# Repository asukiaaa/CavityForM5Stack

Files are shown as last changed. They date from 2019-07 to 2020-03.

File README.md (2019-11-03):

# CavityForM5Stack

PCBs to create a cavity for M5Stack.

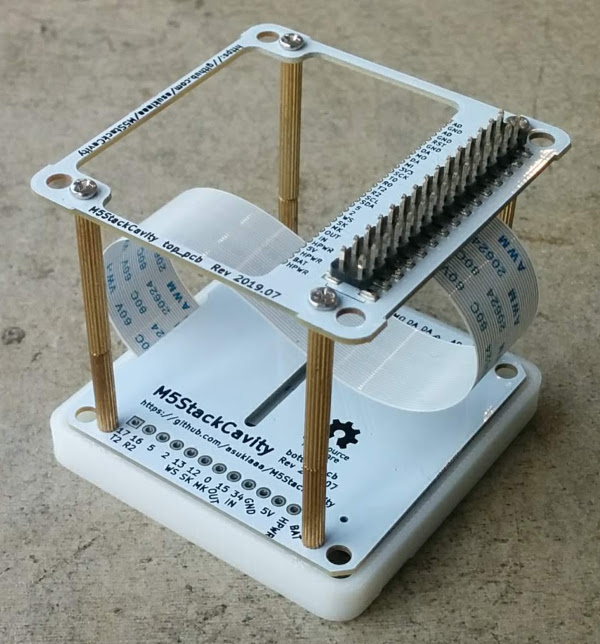
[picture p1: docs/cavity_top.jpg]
cavity_top

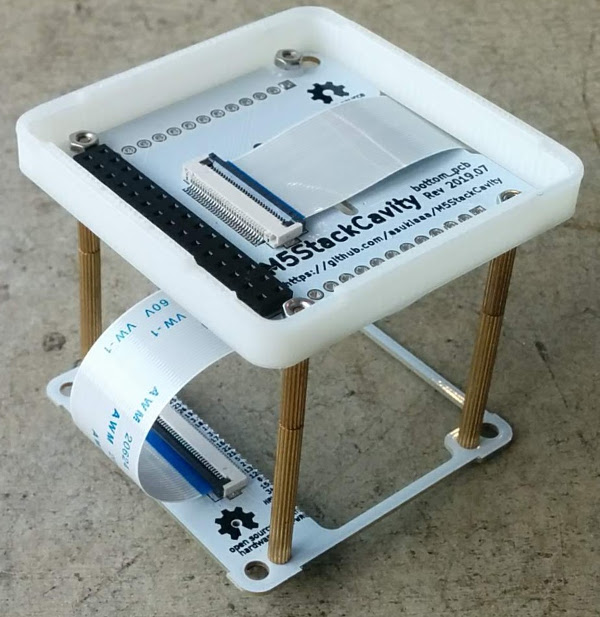
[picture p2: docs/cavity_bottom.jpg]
cavity_bottom


# License

MIT

# References

- [CavityForM5Stack ピンソケット、ブレッドボード無し](https://www.switch-science.com/catalog/5684/)
- [CavityForM5Stack ピンソケット、ブレッドボード付き](https://www.switch-science.com/catalog/5685/)
- [M5StackのStackに背の高い部品を利用できるM5StackCavityを作ってみた](http://asukiaaa.blogspot.com/2019/08/m5stackstackm5stackcavity.html)

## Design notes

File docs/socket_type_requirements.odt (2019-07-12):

Put header for top_pcb and put socket for bottom_pcb.

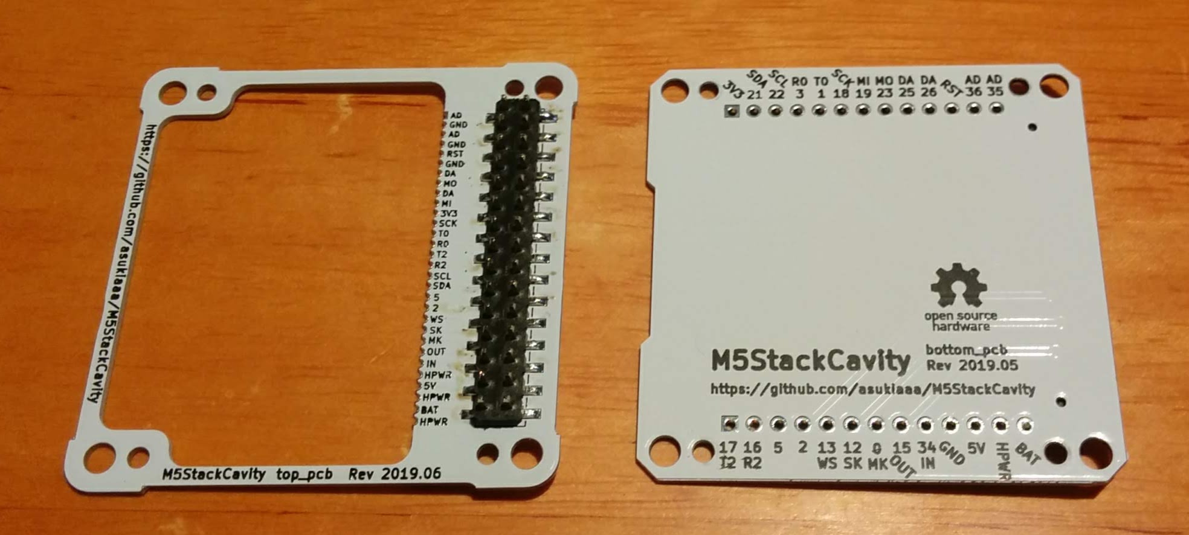
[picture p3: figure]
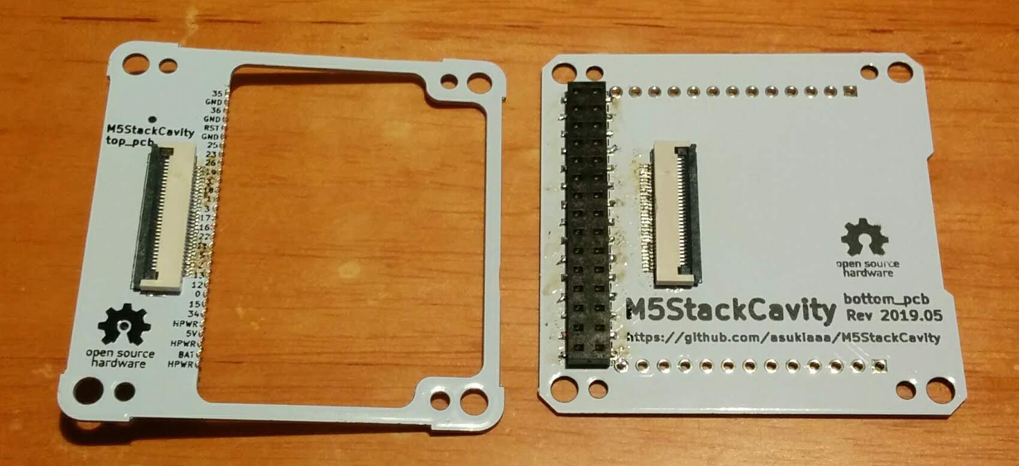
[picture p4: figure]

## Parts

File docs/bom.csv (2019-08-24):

Name | Number | Url | Memo
top_pcb | 1 | Attached | Layer--2layers PCB Thickness--1.0mm Dimensions--51mm * 51mm Castellated Hole--Yes PCB Color--White Surface Finish--HASL Lead Free Copper Weight--1oz Different Design:--1
bottom_pcb | 1 | Attached | Layer--2layers PCB Thickness--1.0mm Dimensions--50mm * 50mm Castellated Hole--No PCB Color--White Surface Finish--HASL Lead Free Copper Weight--1oz Different Design:--1
M5 Stack Joint | 1 pair | https://ja.aliexpress.com/store/product/M5Stack-Official-Stock-Offer-2x15-Pin-Headers-Socket-2-54mm-Male-Female-4-Pair-Connector-for/3226069_32840923472.html | Use header for top_pcb, socket for bottom_pcb
0.5mm pitch 30 pins FPC Connector | 2 | https://ja.aliexpress.com/item/32956902542.html
2.54m pitch 1x13 PinSocket white | 2 |  | Put pinsocket on front side of bottom_pcb. I don't mind bendor.

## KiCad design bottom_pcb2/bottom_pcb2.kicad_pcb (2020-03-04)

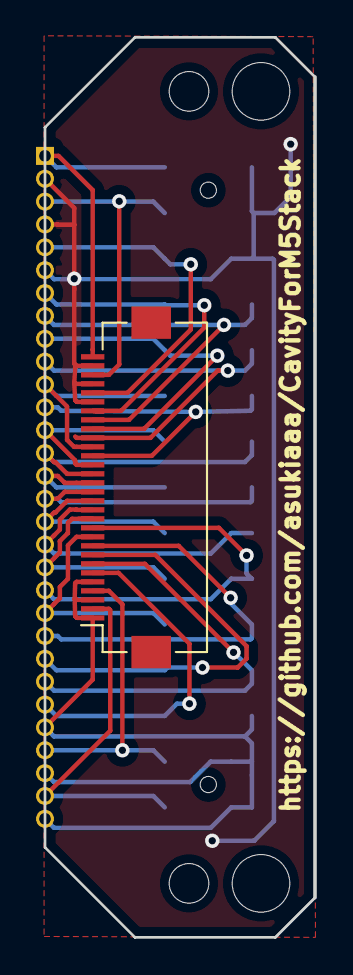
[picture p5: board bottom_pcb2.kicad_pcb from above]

Board: 2 copper layers, 15.0 x 50.0 mm, 7 parts (1 on the bottom side), 26 nets.

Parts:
J1: socket; PinSocket_2x15_P2.54mm_Vertical_SMD_just_for_M5Stack_bottom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
J3: free_holes; PinHeader_1x30_P1.27mm_Vertical_without_silks
Jv: flat_cable_connector; Hirose_FH12-30S-0.5SH_1x30-1MP_P0.50mm_Horizontal
REF3, REF8: MountingHole_2.2mm_M2
REF4, REF9: MountingHole_3.2mm_M3

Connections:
+3V3: J1.11, J3.11, Jv.20
+5V: J1.27, J3.27, Jv.4
+BATT: J1.29, J3.29, Jv.2
G0: J1.23, J3.23, Jv.8
G1: J1.13, J3.13, Jv.18
G2: J1.20, J3.20, Jv.11
G3: J1.14, J3.14, Jv.17
G5: J1.19, J3.19, Jv.12
G12: J1.22, J3.22, Jv.9
G13: J1.21, J3.21, Jv.10
G15: J1.24, J3.24, Jv.7
G16: J1.16, J3.16, Jv.15
G17: J1.15, J3.15, Jv.16
G18: J1.12, J3.12, Jv.19
G19: J1.10, J3.10, Jv.21
G21: J1.18, J3.18, Jv.13
G22: J1.17, J3.17, Jv.14
G23: J1.8, J3.8, Jv.23
G25: J1.7, J3.7, Jv.24
G26: J1.9, J3.9, Jv.22
G34: J1.25, J3.25, Jv.6
G35: J1.1, J3.1, Jv.30
G36: J1.3, J3.3, Jv.28
GND: J1.2, J1.4, J1.6, J3.2, J3.4, J3.6, Jv.25, Jv.27, Jv.29
HPWR: J1.26, J1.28, J1.30, J3.26, J3.28, J3.30, Jv.1, Jv.3, Jv.5
RST: J1.5, J3.5, Jv.26

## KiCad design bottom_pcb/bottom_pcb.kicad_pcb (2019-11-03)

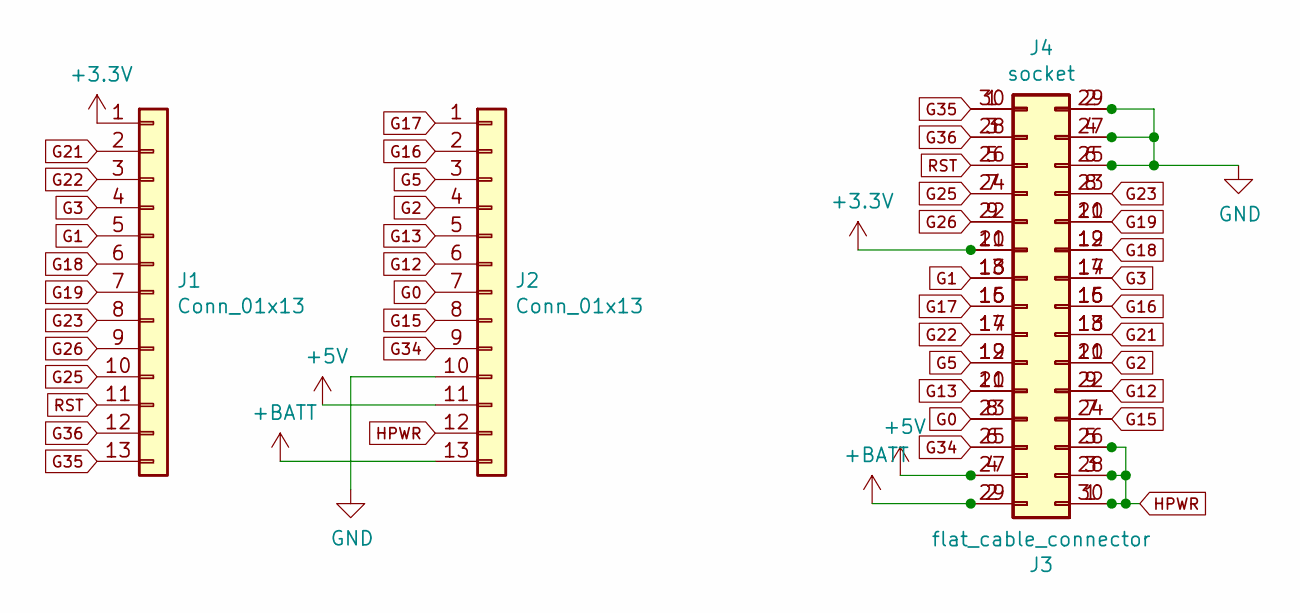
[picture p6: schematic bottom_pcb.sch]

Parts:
J1, J2: Conn_01x13; PinSocket_1x13_P2.54mm_Vertical_without_silks
J3: flat_cable_connector; Hirose_FH12-30S-0.5SH_1x30-1MP_P0.50mm_Horizontal
J4: socket; PinSocket_2x15_P2.54mm_Vertical_SMD_just_for_M5Stack_bottom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

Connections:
+3V3: J1.1, J3.20, J4.11
+5V: J2.11, J3.4, J4.27
+BATT: J2.13, J3.2, J4.29
G0: J2.7, J3.8, J4.23
G1: J1.5, J3.18, J4.13
G2: J2.4, J3.11, J4.20
G3: J1.4, J3.17, J4.14
G5: J2.3, J3.12, J4.19
G12: J2.6, J3.9, J4.22
G13: J2.5, J3.10, J4.21
G15: J2.8, J3.7, J4.24
G16: J2.2, J3.15, J4.16
G17: J2.1, J3.16, J4.15
G18: J1.6, J3.19, J4.12
G19: J1.7, J3.21, J4.10
G21: J1.2, J3.13, J4.18
G22: J1.3, J3.14, J4.17
G23: J1.8, J3.23, J4.8
G25: J1.10, J3.24, J4.7
G26: J1.9, J3.22, J4.9
G34: J2.9, J3.6, J4.25
G35: J1.13, J3.30, J4.1
G36: J1.12, J3.28, J4.3
GND: J2.10, J3.25, J3.27, J3.29, J4.2, J4.4, J4.6
HPWR: J2.12, J3.1, J3.3, J3.5, J4.26, J4.28, J4.30
RST: J1.11, J3.26, J4.5

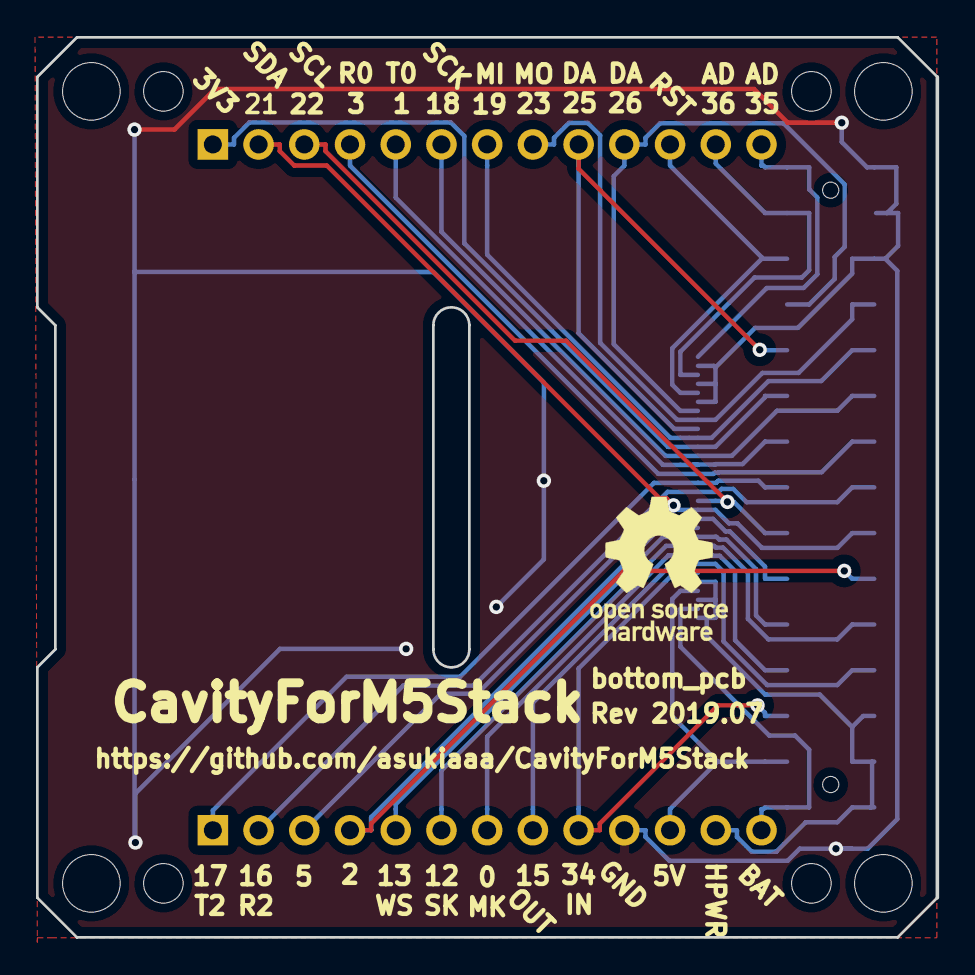
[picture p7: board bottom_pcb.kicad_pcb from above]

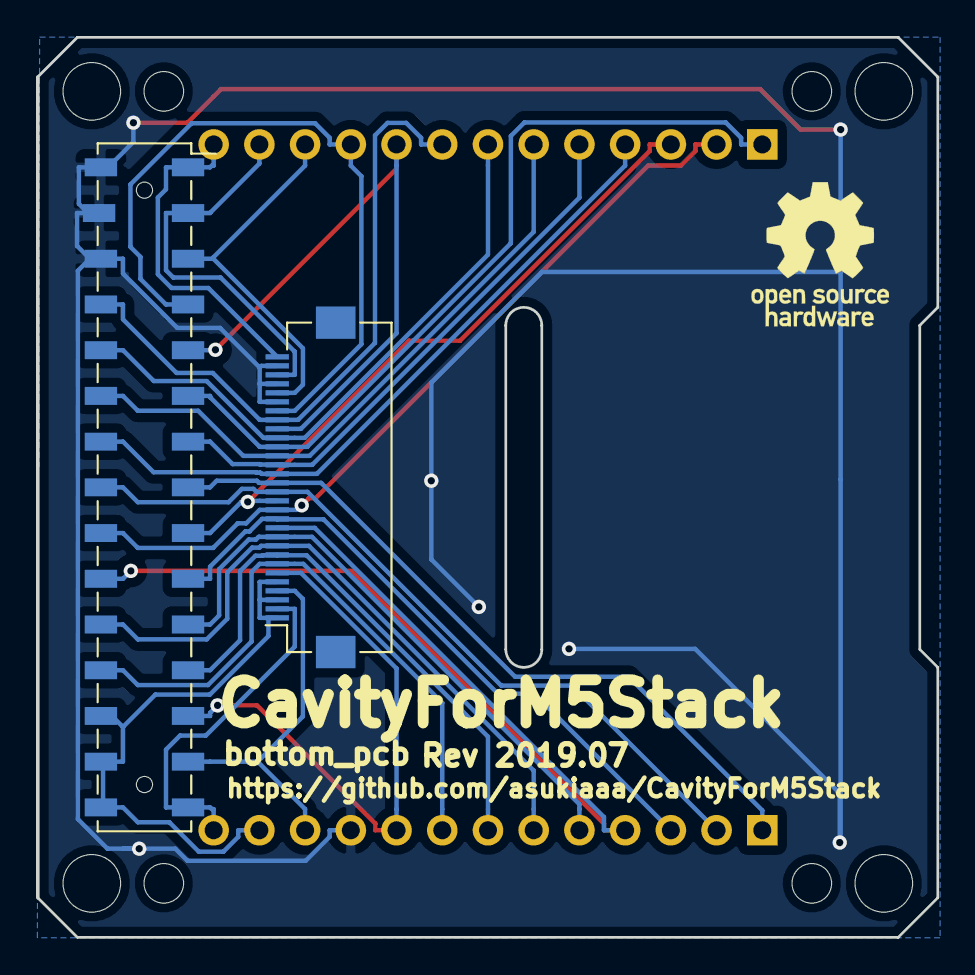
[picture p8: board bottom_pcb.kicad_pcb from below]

Board: 2 copper layers, 50.0 x 50.0 mm, 14 parts (3 on the bottom side), 26 nets.

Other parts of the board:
OSHWREF1, OSHWREF2: OSHW-Logo_7.5x8mm_SilkScreen
REF1, REF4, REF6, REF9: MountingHole_3.2mm_M3
REF2, REF3, REF7, REF8: MountingHole_2.2mm_M2

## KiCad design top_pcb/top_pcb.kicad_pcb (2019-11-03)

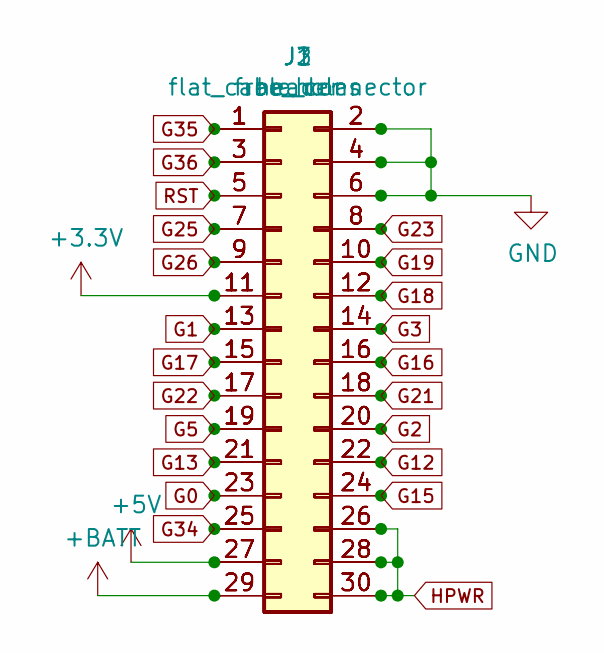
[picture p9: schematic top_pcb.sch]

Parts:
J1: flat_cable_connector; Hirose_FH12-30S-0.5SH_1x30-1MP_P0.50mm_Horizontal
J2: header; PinHeader_2x15_P2.54mm_Vertical_SMD_for_M5Stack
J3: free_holes; PinHeader_1x30_P1.27mm_Vertical_without_silks

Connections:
+3V3: J1.11, J2.11, J3.11
+5V: J1.27, J2.27, J3.27
+BATT: J1.29, J2.29, J3.29
G0: J1.23, J2.23, J3.23
G1: J1.13, J2.13, J3.13
G2: J1.20, J2.20, J3.20
G3: J1.14, J2.14, J3.14
G5: J1.19, J2.19, J3.19
G12: J1.22, J2.22, J3.22
G13: J1.21, J2.21, J3.21
G15: J1.24, J2.24, J3.24
G16: J1.16, J2.16, J3.16
G17: J1.15, J2.15, J3.15
G18: J1.12, J2.12, J3.12
G19: J1.10, J2.10, J3.10
G21: J1.18, J2.18, J3.18
G22: J1.17, J2.17, J3.17
G23: J1.8, J2.8, J3.8
G25: J1.7, J2.7, J3.7
G26: J1.9, J2.9, J3.9
G34: J1.25, J2.25, J3.25
G35: J1.1, J2.1, J3.1
G36: J1.3, J2.3, J3.3
GND: J1.2, J1.4, J1.6, J2.2, J2.4, J2.6, J3.2, J3.4, J3.6
HPWR: J1.26, J1.28, J1.30, J2.26, J2.28, J2.30, J3.26, J3.28, J3.30
RST: J1.5, J2.5, J3.5

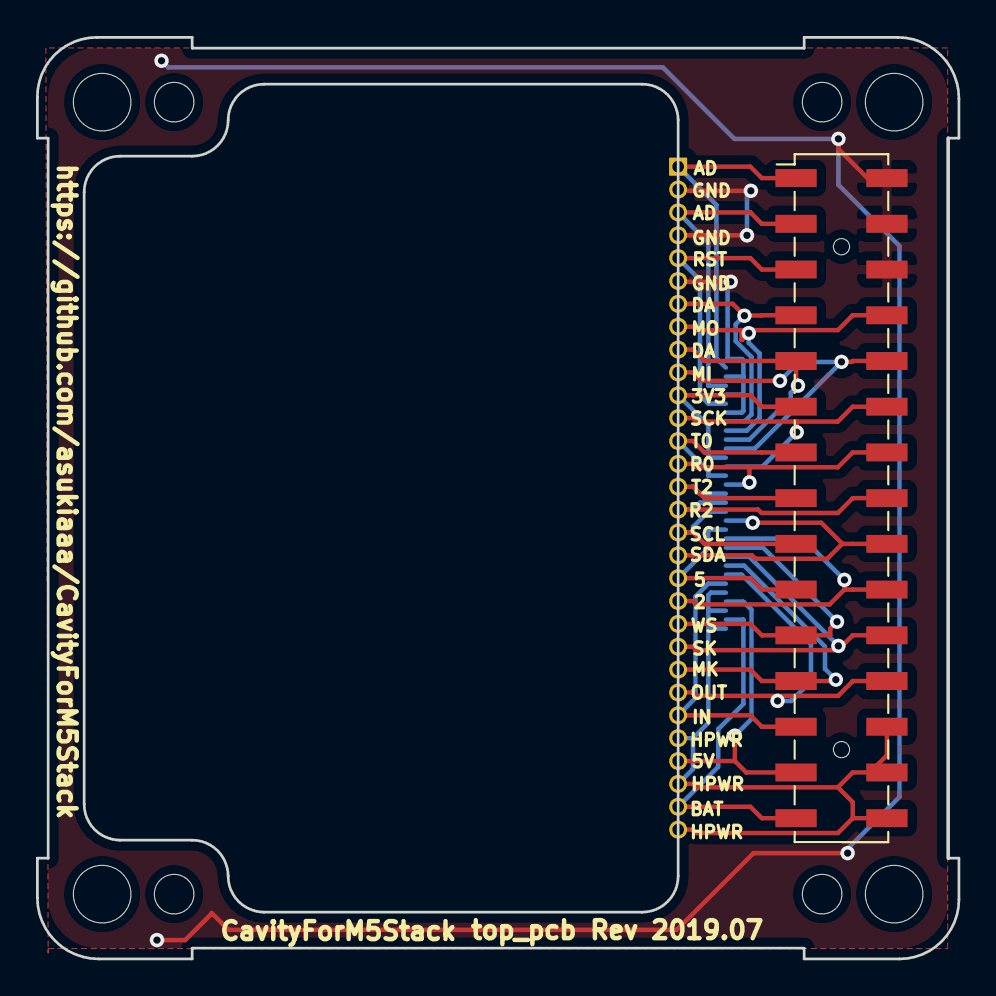
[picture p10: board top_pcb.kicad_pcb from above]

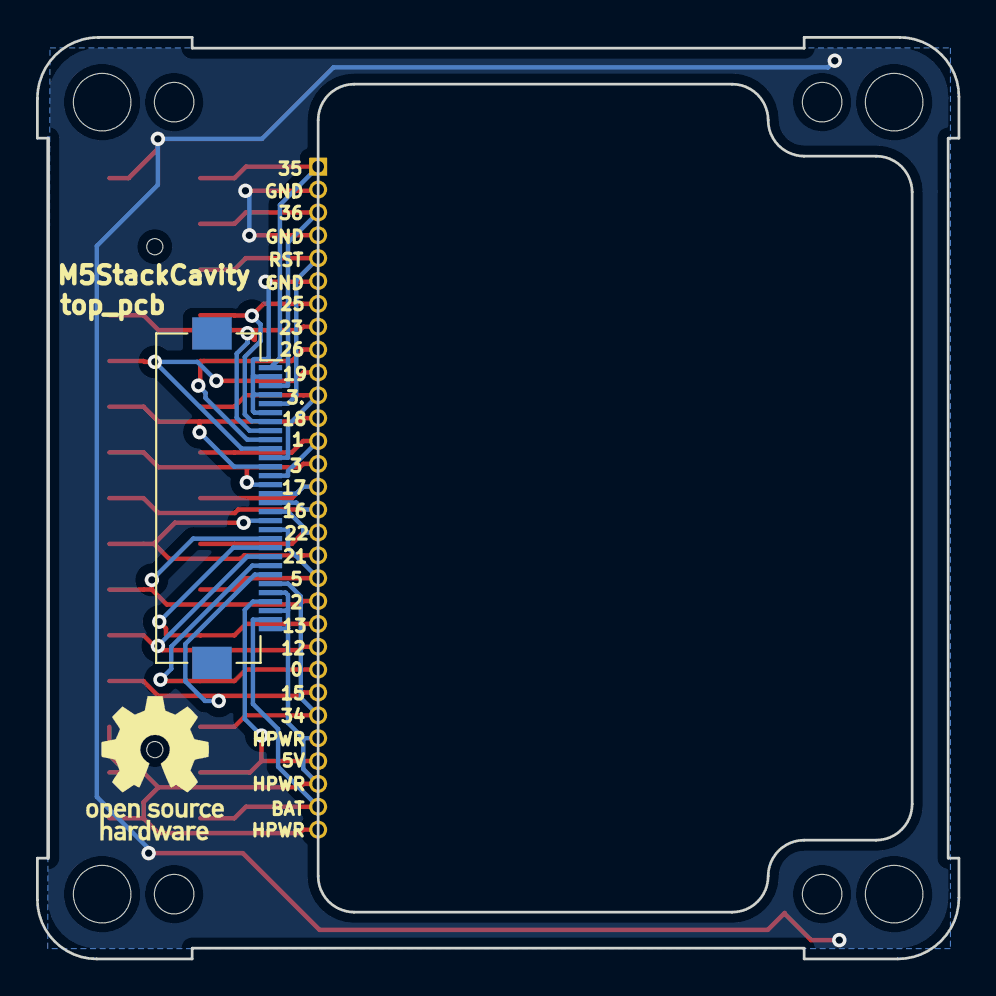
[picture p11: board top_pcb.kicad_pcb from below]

Board: 2 copper layers, 51.2 x 51.2 mm, 16 parts (2 on the bottom side), 26 nets.

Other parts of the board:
OSHWREF2: OSHW-Logo_7.5x8mm_SilkScreen
REF1, REF4, REF6, REF9: MountingHole_3.2mm_M3
REF2, REF3, REF7, REF8: MountingHole_2.2mm_M2
corner1, corner4: corner_edge1
corner2, corner3: corner_edge2

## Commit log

2019-05-29 Add space for flat cable to bottom pcb
    [bottom_pcb-B.Cu.gbr, bottom_pcb-B.Mask.gbr, bottom_pcb-B.Paste.gbr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]
2019-06-01 Change connector position on top_pcb
    [top_pcb-B.Cu.gbr, top_pcb-B.Mask.gbr, top_pcb-B.Paste.gbr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]
2019-06-23 Assign corner edge to top_pcb
    [top_pcb.kicad_pcb]
2019-06-23 Add hole to top_pcb
    [top_pcb.kicad_pcb, top_pcb.sch]
2019-06-23 Update gerber files
    [top_pcb-B.Cu.gbr, top_pcb-B.Mask.gbr, top_pcb-B.SilkS.gbr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]
2019-07-09 Update center connector position on bottom_pcb
    [bottom_pcb.kicad_pcb]
2019-07-12 Add center hole to bottom_pcb
    [bottom_pcb.kicad_pcb]
2019-07-12 Remove redundant footprints from top_pcb
2019-07-12 Change pad size smaller for pin socket on top_pcb
    [top_pcb.kicad_pcb]
2019-07-12 Export gerber files to order rev 2019.07
    [bottom_pcb-B.Cu.gbr, bottom_pcb-B.Mask.gbr, bottom_pcb-B.SilkS.gbr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]
2019-07-12 Add bom.csv
    [bom.csv]
2019-08-24 Add pinsockets to bom
    [bom.csv]
2019-11-03 Rename project name to CavityForM5Stack from M5StackCavity
    [bottom_pcb.kicad_pcb, top_pcb.kicad_pcb]
2020-03-04 Add bottom_pcb2
    [bottom_pcb2.kicad_pcb, bottom_pcb2.sch]
2020-03-04 Remove redundant gerber files for bottom_pcb and top_pcb
    [bottom_pcb-B_Cu.gbr, bottom_pcb-B_Mask.gbr, bottom_pcb-B_Paste.gbr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]
2020-03-04 Change label layer for bottom_pcb2
    [bottom_pcb2.kicad_pcb]
